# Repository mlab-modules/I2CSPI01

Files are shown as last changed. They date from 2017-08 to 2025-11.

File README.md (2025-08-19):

# I2CSPI01 - I2C to SPI bridge

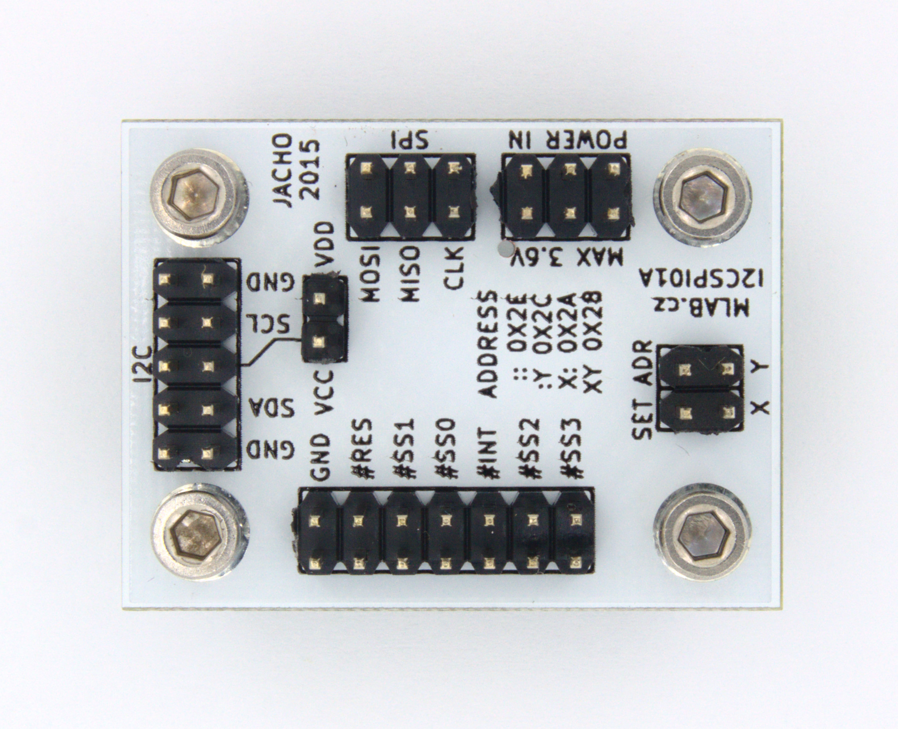
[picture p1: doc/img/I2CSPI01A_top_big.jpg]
I2CSPI01A


The I2CSPI01 module is designed for systems where a microcontroller with only an I2C interface needs to communicate with one or more SPI peripherals. It acts as a bridge that translates I2C commands into SPI signals, allowing integration of SPI devices such as ADCs, DACs, memory chips, or sensors into an I2C-based architecture. This simplifies wiring and reduces the number of required signals.

## Features

* I2C to SPI bridge based on SC18IS602B
* Supports up to four SPI slave devices
* Unused chip-select pins configurable as GPIO
* SPI clock modes: 0, 1, 2, 3
* SPI speed configurable: 58 kHz to 1.843 MHz
* GPIOs support multiple modes: quasi-bidirectional, push-pull, input-only, open-drain
* 200-byte internal buffer
* Operates as I2C slave and SPI master
* 3.3V supply voltage

## Specifications

| Parameter | Value |
| --- | --- |
| Power Supply | Max. 3.6 V |
| Dimensions | 40.13 x 30.00 x 16 mm |
| Interface | I2C (up to 400 kHz), SPI (up to 1.843 MHz) |
| IC Used | SC18IS602B |

## Assembly Notes

* One via must be drilled due to a PCB short.
* J5 header is not functional due to PCB layout issue.

## Resources

* [SC18IS602B Datasheet](https://www.nxp.com/docs/en/data-sheet/SC18IS602B.pdf)
* [Buy from UST](https://www.ust.cz/about/)

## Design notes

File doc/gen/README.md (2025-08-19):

# PCB

Board size: 29.97x40.13 mm (1.18x1.58 inches)

- This is the size of the rectangle that contains the board
- Thickness: 1.6 mm (63 mils)
- Material: FR4
- Finish: HAL
- Layers: 2
- Copper thickness: 35 µm

Solder mask: TOP / BOTTOM

- Color: Green

Silk screen: TOP / BOTTOM

- Color: White

# Important sizes

Clearance: 0.2 mm (8 mils)

Track width: 0.25 mm (10 mils)

- By design rules: 0.25 mm (10 mils)

Drill: 0.75 mm (30 mils)

- Vias: 0.75 mm (30 mils) [Design: 0.6 mm (24 mils)]
- Pads: 1.0 mm (39 mils)
- The above values are real drill sizes, they add 0.1 mm (4 mils) to plated holes (PTH)

Via: 0.89/0.64 mm (35/25 mils)

- By design rules: 0.89/0.51 mm (35/20 mils)
- Micro via: yes [0.51/0.13 mm (20/5 mils)]
- Buried/blind via: yes
- Total: 1 (thru: 1 buried/blind: 0 micro: 0)

Outer Annular Ring: 0.07 mm (3 mils)

- By design rules: 0.33 mm (13 mils)

Eurocircuits class: 10A
- Using min drill 0.75 mm for an OAR of 0.07 mm

# General stats

Components count: (SMD/THT)

- Top: 0/11 (THT)
- Bottom: 11/0 (SMD)

Defined tracks:

- 0.25 mm (10 mils)
- 0.38 mm (15 mils)
- 0.4 mm (16 mils)
- 0.51 mm (20 mils)
- 0.6 mm (24 mils)
- 0.7 mm (28 mils)

Used tracks:

- 0.25 mm (10 mils) (2) defined: yes
- 0.38 mm (15 mils) (109) defined: yes
- 0.51 mm (20 mils) (24) defined: yes

Defined vias:

Used vias:

- 0.89/0.64 mm (35/25 mils) (Count: 1, Aspect: 1.8 A) defined: no

Holes (excluding vias):

- 0.9 mm (35 mils) (42)
- 3.0 mm (118 mils) (4)

Oval holes:

Drill tools (including vias and computing adjusts and rounding):

- 0.75 mm (30 mils) (1)
- 1.0 mm (39 mils) (42)
- 3.1 mm (122 mils) (4)

Solder paste stats:

Using a paste with 87.75 % alloy, that has an specific gravity for the alloy of 7.4 g/cm³
and 1.0 g/cm³ for the flux. This paste has an specific gravity of  4.15 g/cm³.

The stencil thickness is  0.12 mm.

| Side | Pads with paste | Area [mm²] | Paste [g] |
|---|---|---|---|
| Total  | 36 | 34.52 | 0.17 |

Note: this is just an approximation to the theoretical value. Margins of the solder mask and waste aren't computed.

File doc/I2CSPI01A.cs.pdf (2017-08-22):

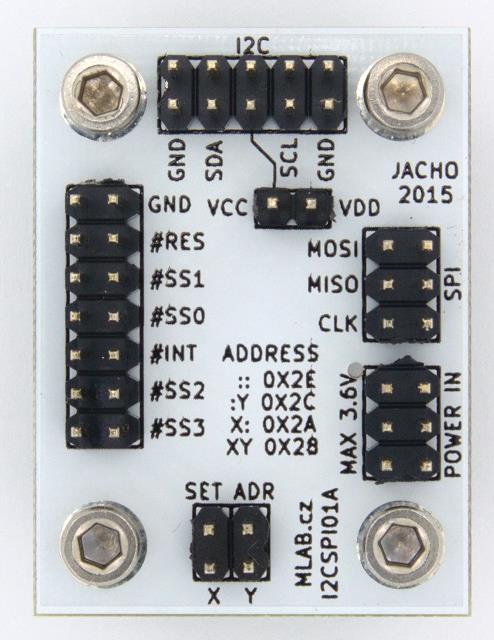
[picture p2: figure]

I2CSPI01A / 2016-02-26 / jacho/ http://www.mlab.cz | 1 / 4
I2CSPI01A | MLAB

# I2C - SPI převodník

Jan Chroust

Modul umožňuje připojení až čtyř zařízení na sběrnici SPI současně. Případné nevyužité piny mohou sloužit jako GPIO.

# 1. Technické parametry

Parametr | Hodnota | Poznámka
Napájení | Max. 3,6 V
Integrovaný obvod | SC18IS602B
Rozhraní | I2C, SPI
Hlavní využití | I2C/SPI převodník
Rozměry | 40.13 x 30.00 x 16 mm | Výška nad základní deskou

I2CSPI01A | MLAB

# 2. Popis konstrukce

## 2.1. Zapojení

I2CSPI01A | MLAB

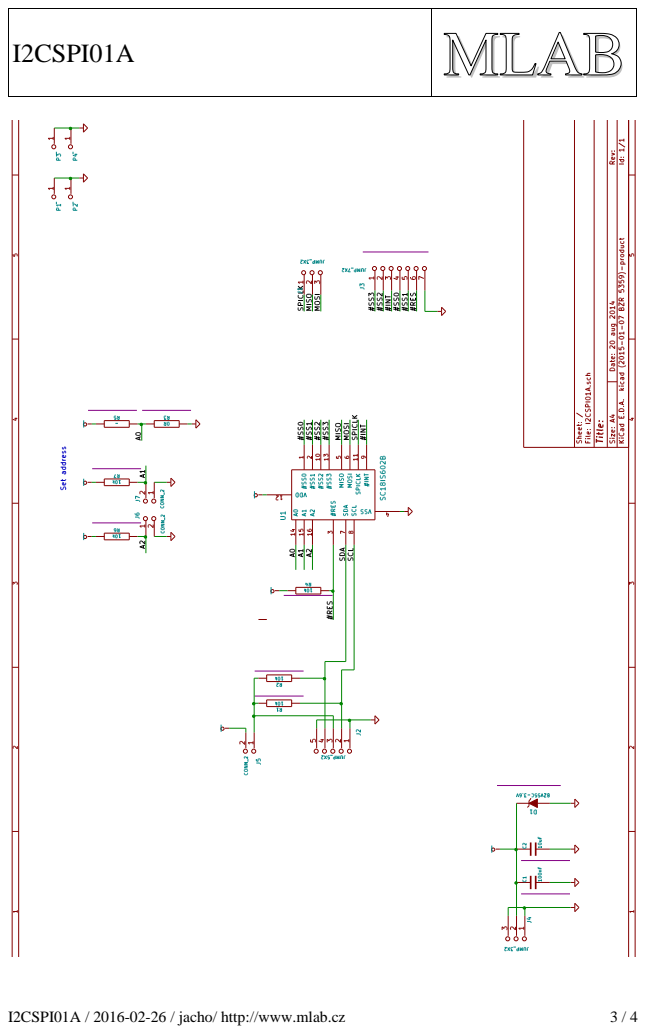
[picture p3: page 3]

I2CSPI01A | MLAB

# 3. Osazení a oživení

## 3.1. Osazení

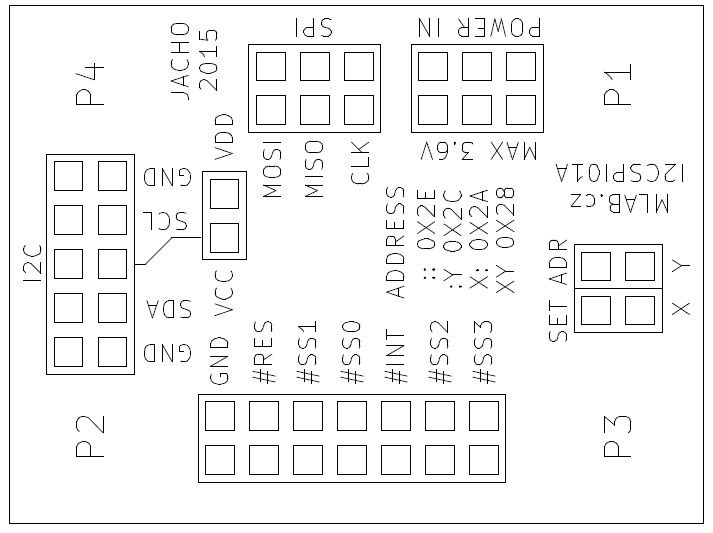
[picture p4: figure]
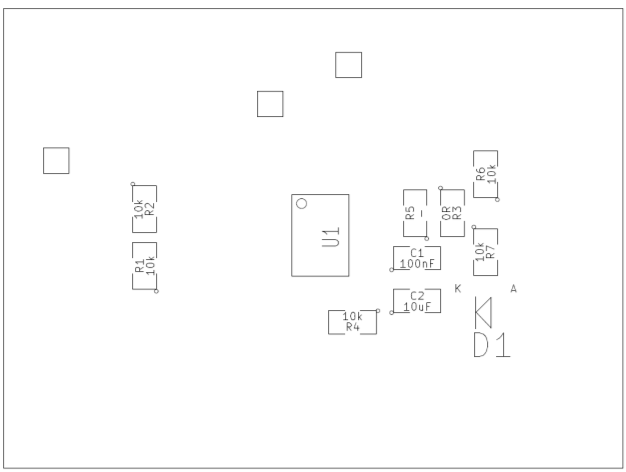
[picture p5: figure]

Označení | Typ | Pouzdro | Počet
J1 | JUMP_3X2 | Pin_Header_Straight_2x03 | 1
R1,R2,R4,R6,R7 | 10k | SMD-0805 | 5
C1 | 100nF | SMD-0805 | 1
C2 | 10uF | SMD-0805 | 1
R3 | 0R | SMD-0805 | 1
R5 | - | SMD-0805 | 1
U1 | SC18IS602B | TSSOP-16 | 1
J4 | JUMP_3X2 | Pin_Header_Straight_2x03 | 1
J3 | JUMP_7X2 | Pin_Header_Straight_2x07 | 1
J2 | JUMP_5X2 | Pin_Header_Straight_2x05 | 1
P1,P2,P3,P4 | _ | MountingHole_3mm | 4
J5,J6,J7 | CONN_2 | Pin_Header_Straight_1x02 | 3
D1 | BZV55C-3,6V | Diode-MiniMELF_Standard | 1

Je potřeba odvrtat jediný prokov na PCB (kvůli zkratu na PCB). Funkce hřebínku J5 odpadá.

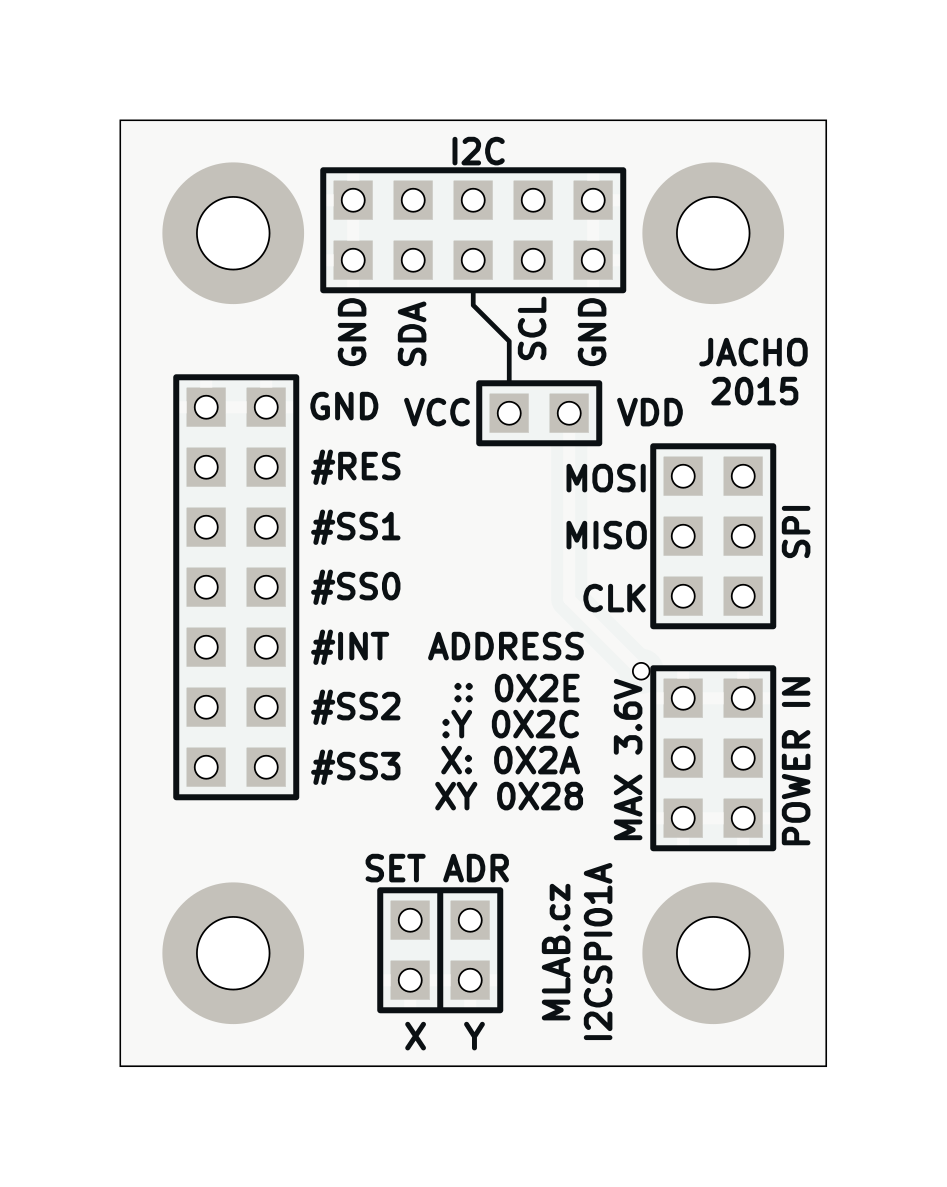
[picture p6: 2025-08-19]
doc/gen/img/I2CSPI01-top.png

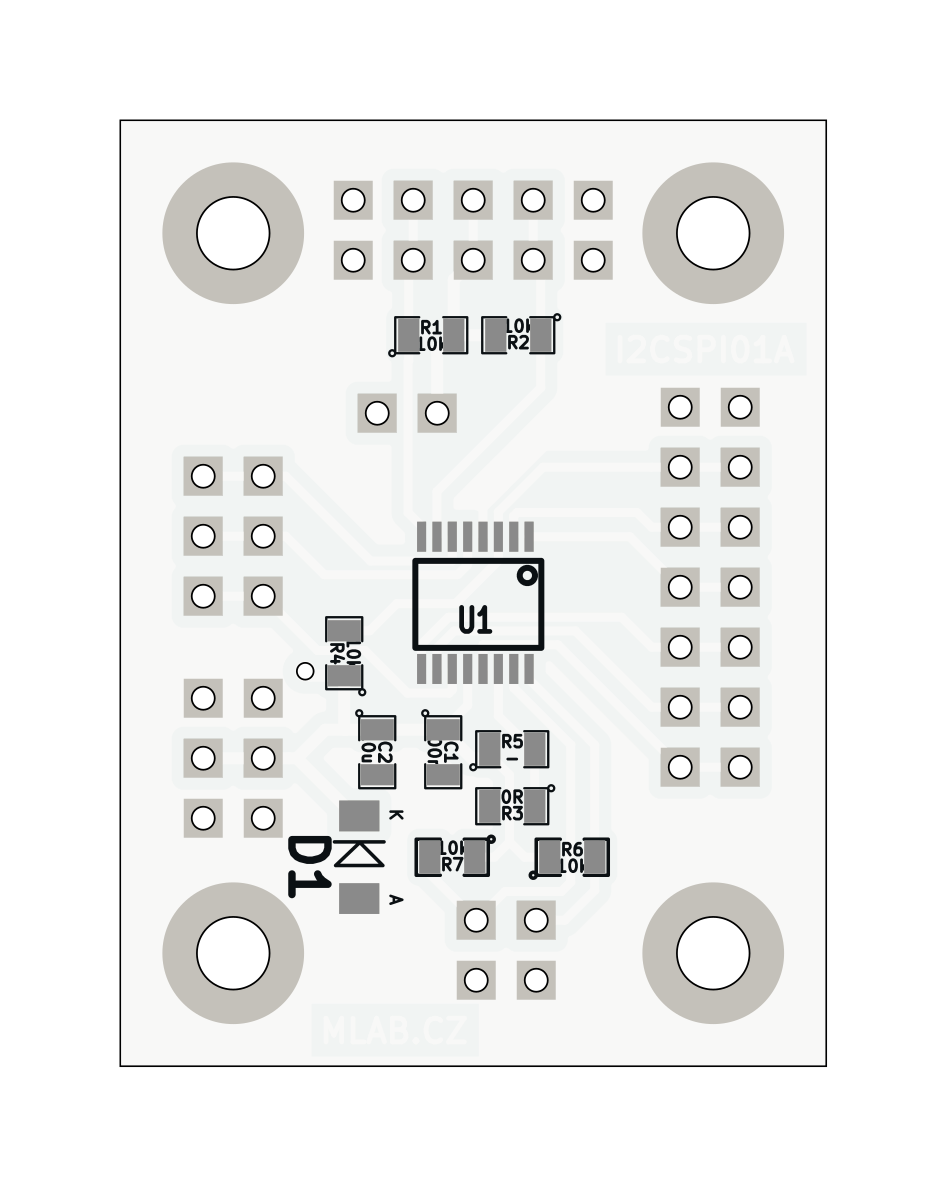
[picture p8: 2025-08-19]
doc/gen/img/I2CSPI01-bottom.png

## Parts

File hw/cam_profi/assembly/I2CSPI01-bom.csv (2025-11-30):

Component | Description | Part | References | Value | Footprint | Quantity Per PCB | Datasheet
1 |  | C_3 | C1 | 100nF | SMD-0805 | 1 | ~
2 |  | C_4 | C2 | 10uF | SMD-0805 | 1 | ~
3 |  | ZENER_2 | D1 | BZV55C-3,6V | Diode-MiniMELF_Standard | 1 | ~
4 |  | CONN_2_6 | J5 | CONN_2 | Pin_Header_Straight_1x02 | 1
5 |  | CONN_2_4 | J6 | CONN_2 | Pin_Header_Straight_1x02 | 1
6 |  | CONN_2_5 | J7 | CONN_2 | Pin_Header_Straight_1x02 | 1
7 |  | JUMP_3X2_3 | J1 | JUMP_3X2 | Pin_Header_Straight_2x03 | 1
8 |  | JUMP_3X2_4 | J4 | JUMP_3X2 | Pin_Header_Straight_2x03 | 1
9 |  | JUMP_5X2_2 | J2 | JUMP_5X2 | Pin_Header_Straight_2x05 | 1
10 |  | JUMP_7X2_2 | J3 | JUMP_7X2 | Pin_Header_Straight_2x07 | 1 | ~
11 |  | R_14 | R3 | 0R | SMD-0805 | 1 | ~
12 |  | R_10 | R1 | 10k | SMD-0805 | 1 | ~
13 |  | R_9 | R2 | 10k | SMD-0805 | 1 | ~
14 |  | R_8 | R4 | 10k | SMD-0805 | 1 | ~
15 |  | R_11 | R6 | 10k | SMD-0805 | 1 | ~
16 |  | R_12 | R7 | 10k | SMD-0805 | 1 | ~
17 |  | R_13 | R5 | - | SMD-0805 | 1 | ~
18 |  | SC18IS602B_2 | U1 | SC18IS602B | TSSOP-16 | 1

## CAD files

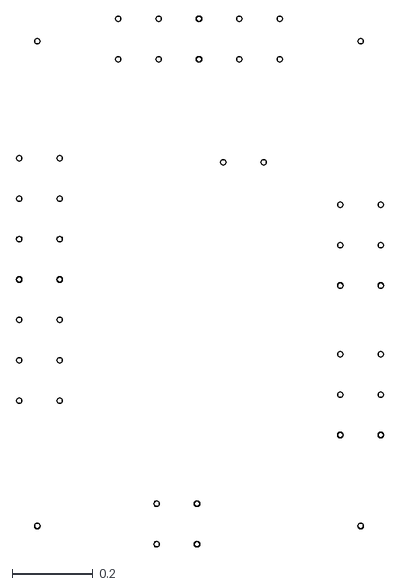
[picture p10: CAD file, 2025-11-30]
doc/gen/dxf/I2CSPI01-User_Eco1.dxf
0.909 x 1.31

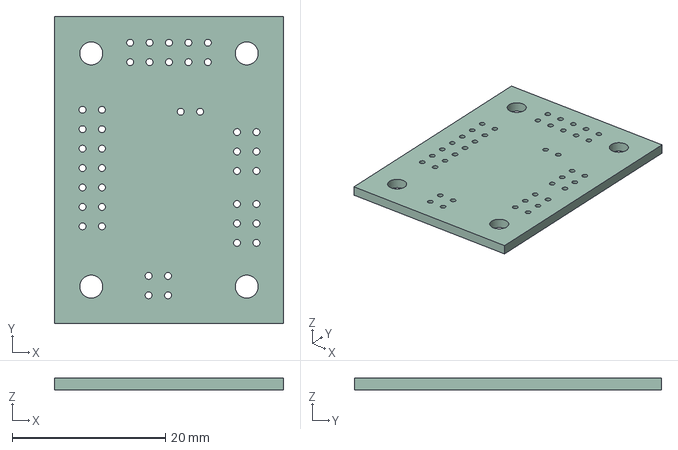
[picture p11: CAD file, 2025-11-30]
doc/gen/I2CSPI01.step
30.0 x 40.1 x 1.51 mm

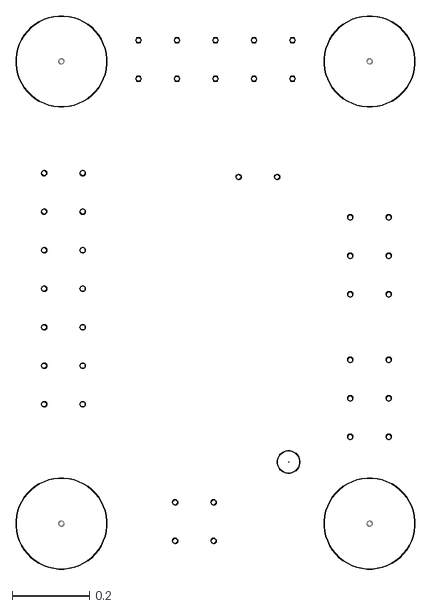
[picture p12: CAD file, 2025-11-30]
doc/gen/dxf/I2CSPI01-B_Adhesive.dxf
1.04 x 1.44

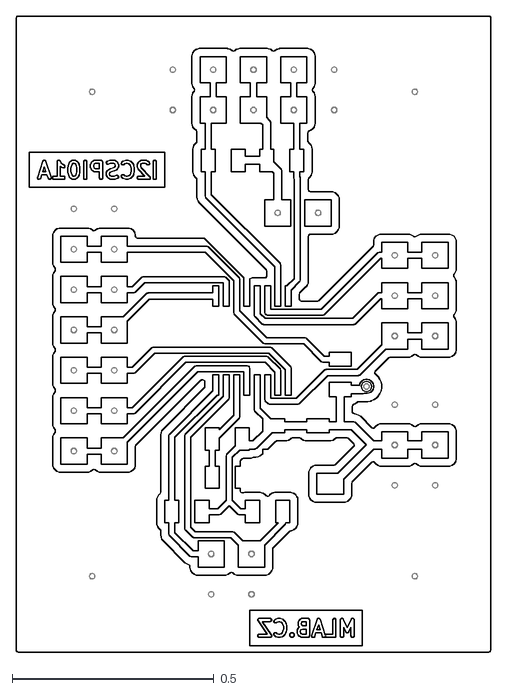
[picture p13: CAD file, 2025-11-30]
doc/gen/dxf/I2CSPI01-B_Cu.dxf
1.18 x 1.58

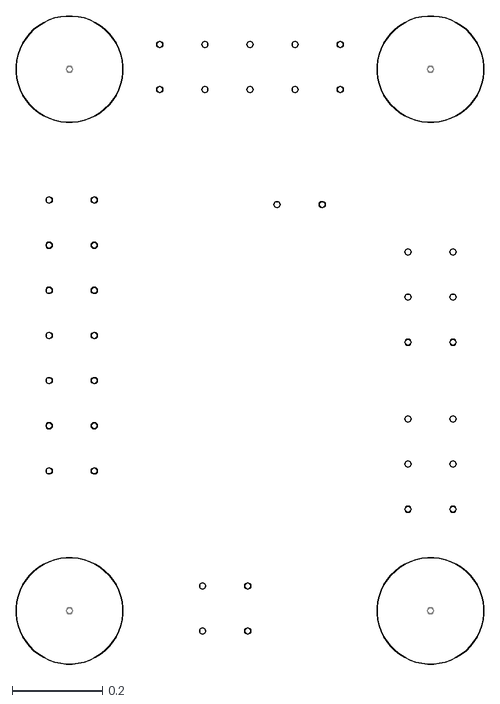
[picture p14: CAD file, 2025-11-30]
doc/gen/dxf/I2CSPI01-F_Adhesive.dxf
1.04 x 1.44

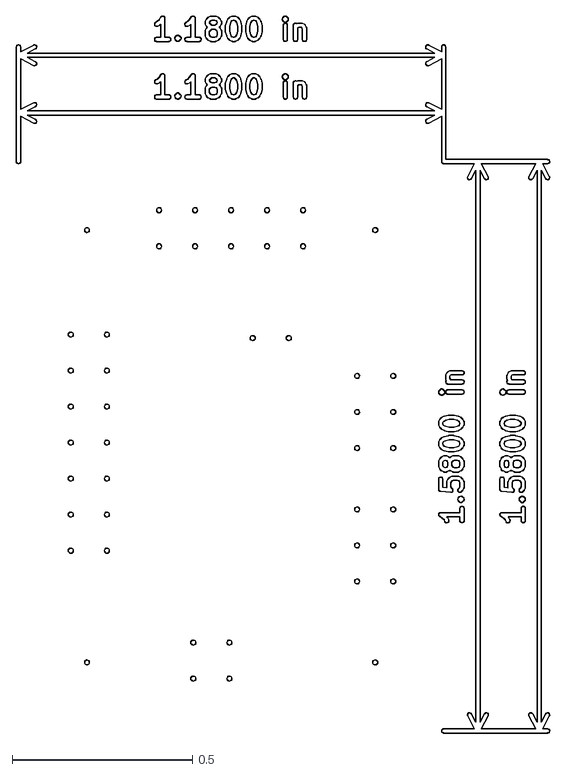
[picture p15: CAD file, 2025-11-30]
doc/gen/dxf/I2CSPI01-User_Drawings.dxf
1.48 x 1.99

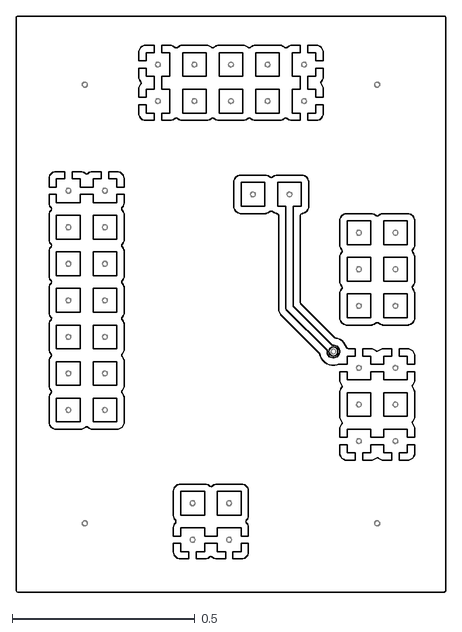
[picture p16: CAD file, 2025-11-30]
doc/gen/dxf/I2CSPI01-F_Cu.dxf
1.18 x 1.58

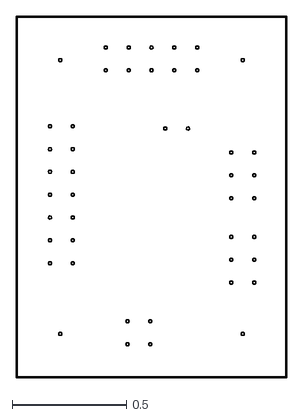
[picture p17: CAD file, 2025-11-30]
doc/gen/dxf/I2CSPI01-Edge_Cuts.dxf
1.18 x 1.58

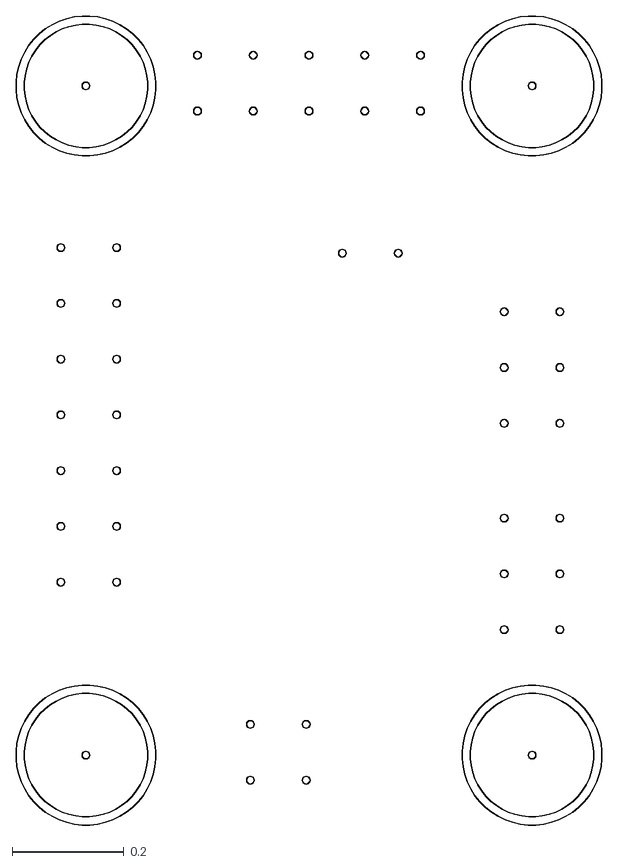
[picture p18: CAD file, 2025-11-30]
doc/gen/dxf/I2CSPI01-User_Comments.dxf
1.05 x 1.45

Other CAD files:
doc/gen/dxf/I2CSPI01-B_Mask.dxf
doc/gen/dxf/I2CSPI01-B_Paste.dxf
doc/gen/dxf/I2CSPI01-B_Silkscreen.dxf
doc/gen/dxf/I2CSPI01-F_Mask.dxf
doc/gen/dxf/I2CSPI01-F_Paste.dxf
doc/gen/dxf/I2CSPI01-F_Silkscreen.dxf

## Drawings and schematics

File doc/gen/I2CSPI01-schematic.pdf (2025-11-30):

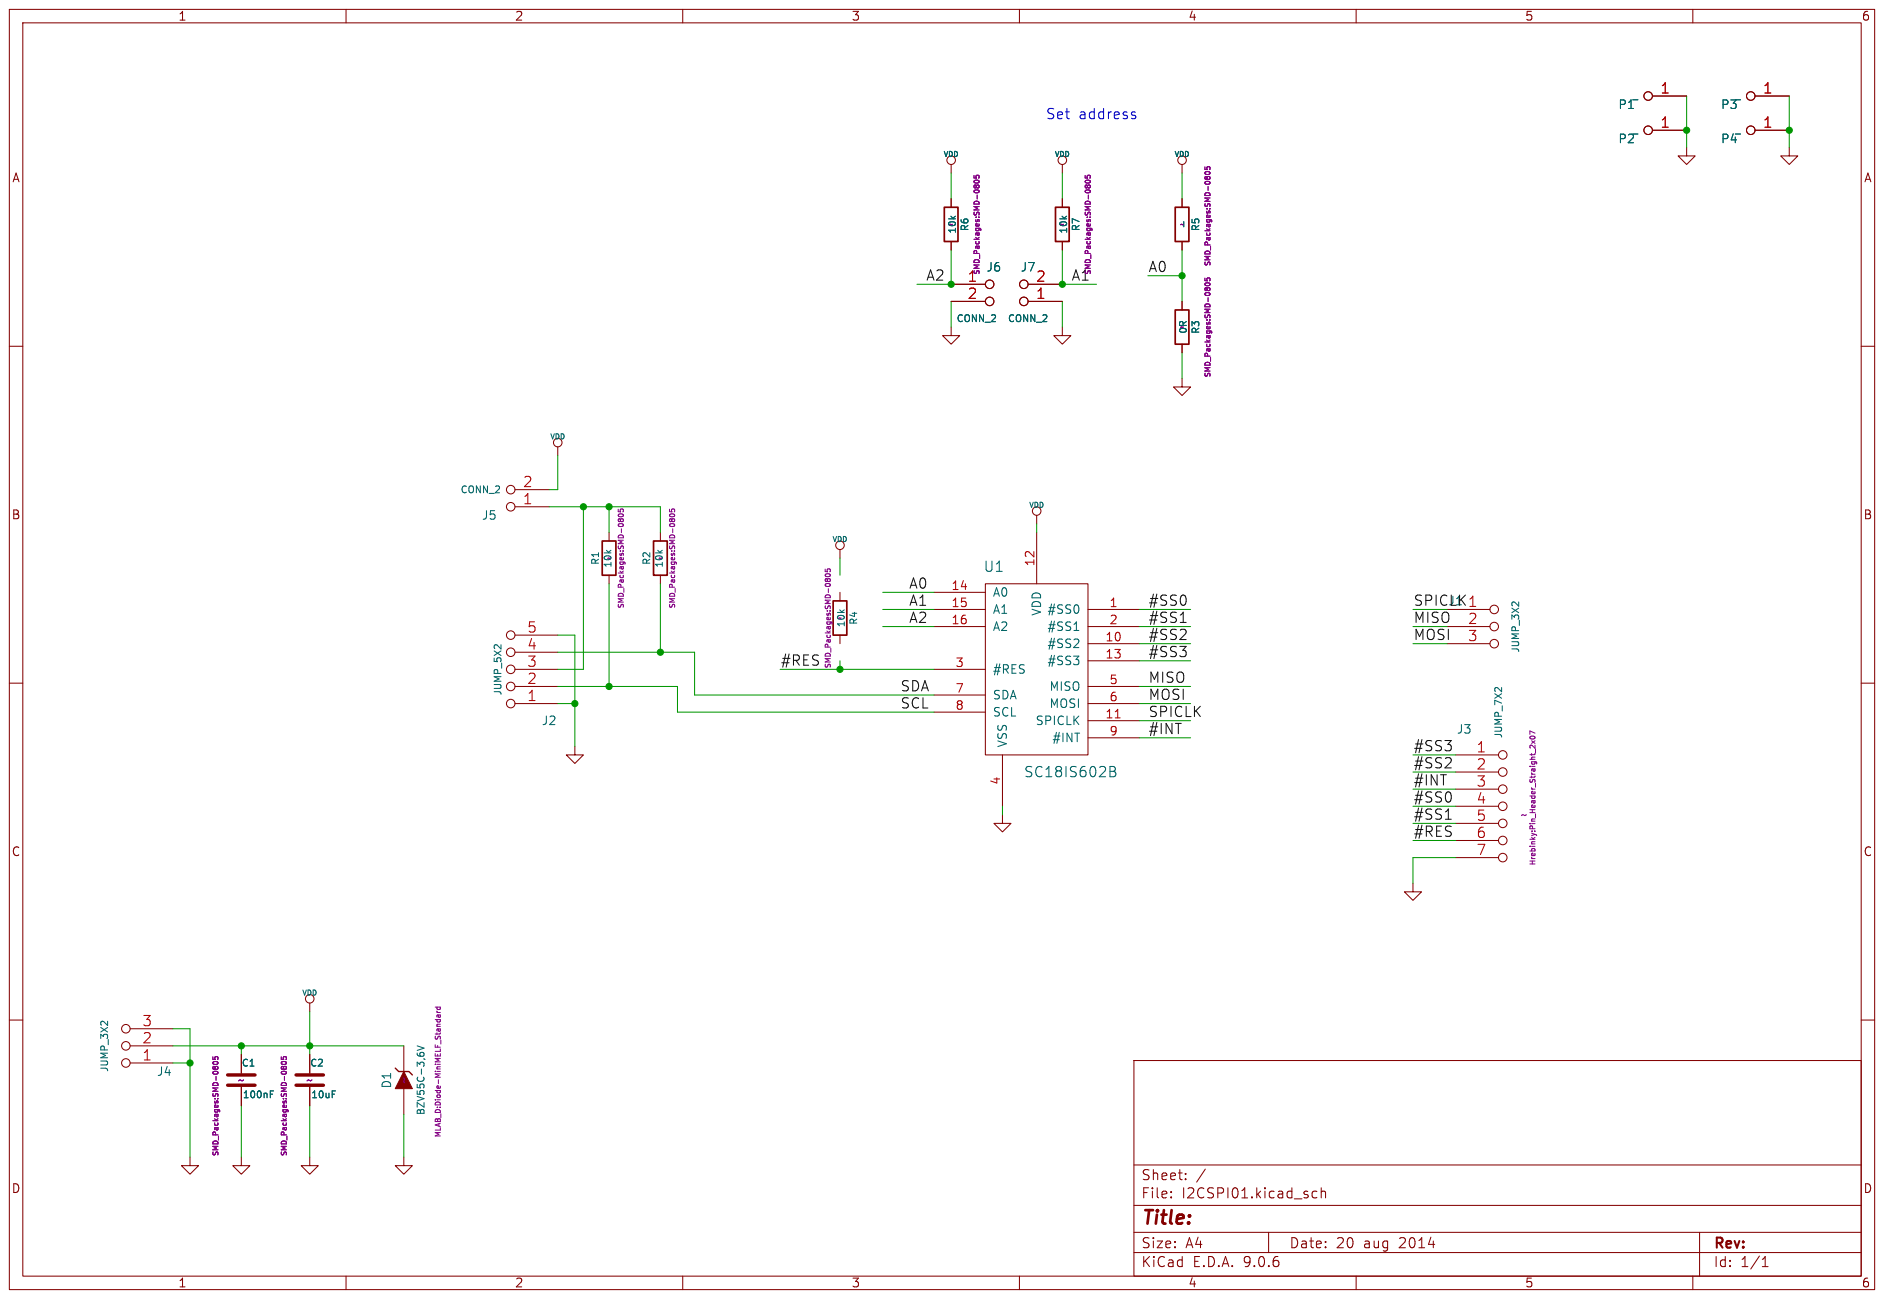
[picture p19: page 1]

Id: 1/1 Title: File: I2CSPI01.kicad_sch Sheet: / C1

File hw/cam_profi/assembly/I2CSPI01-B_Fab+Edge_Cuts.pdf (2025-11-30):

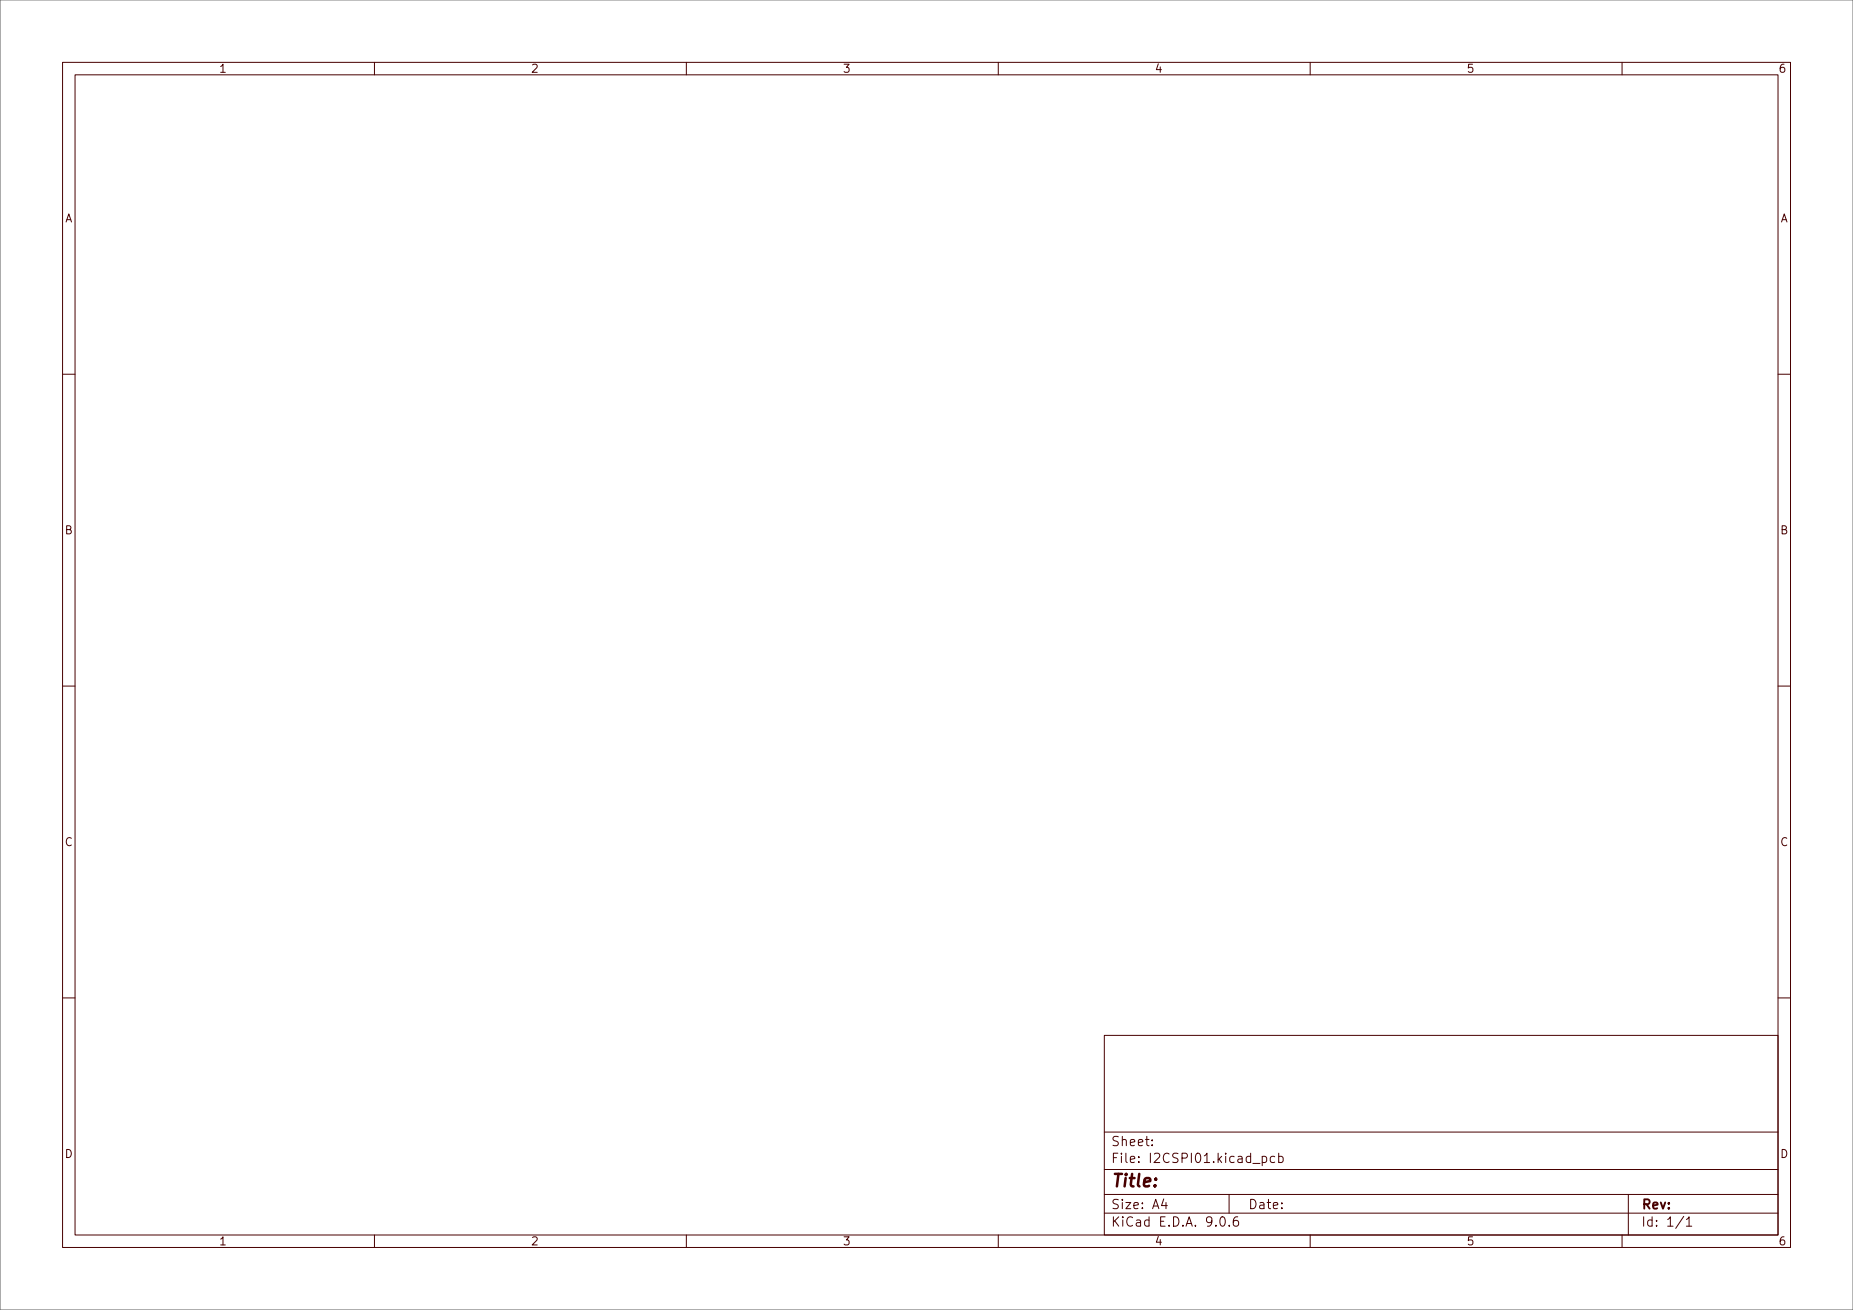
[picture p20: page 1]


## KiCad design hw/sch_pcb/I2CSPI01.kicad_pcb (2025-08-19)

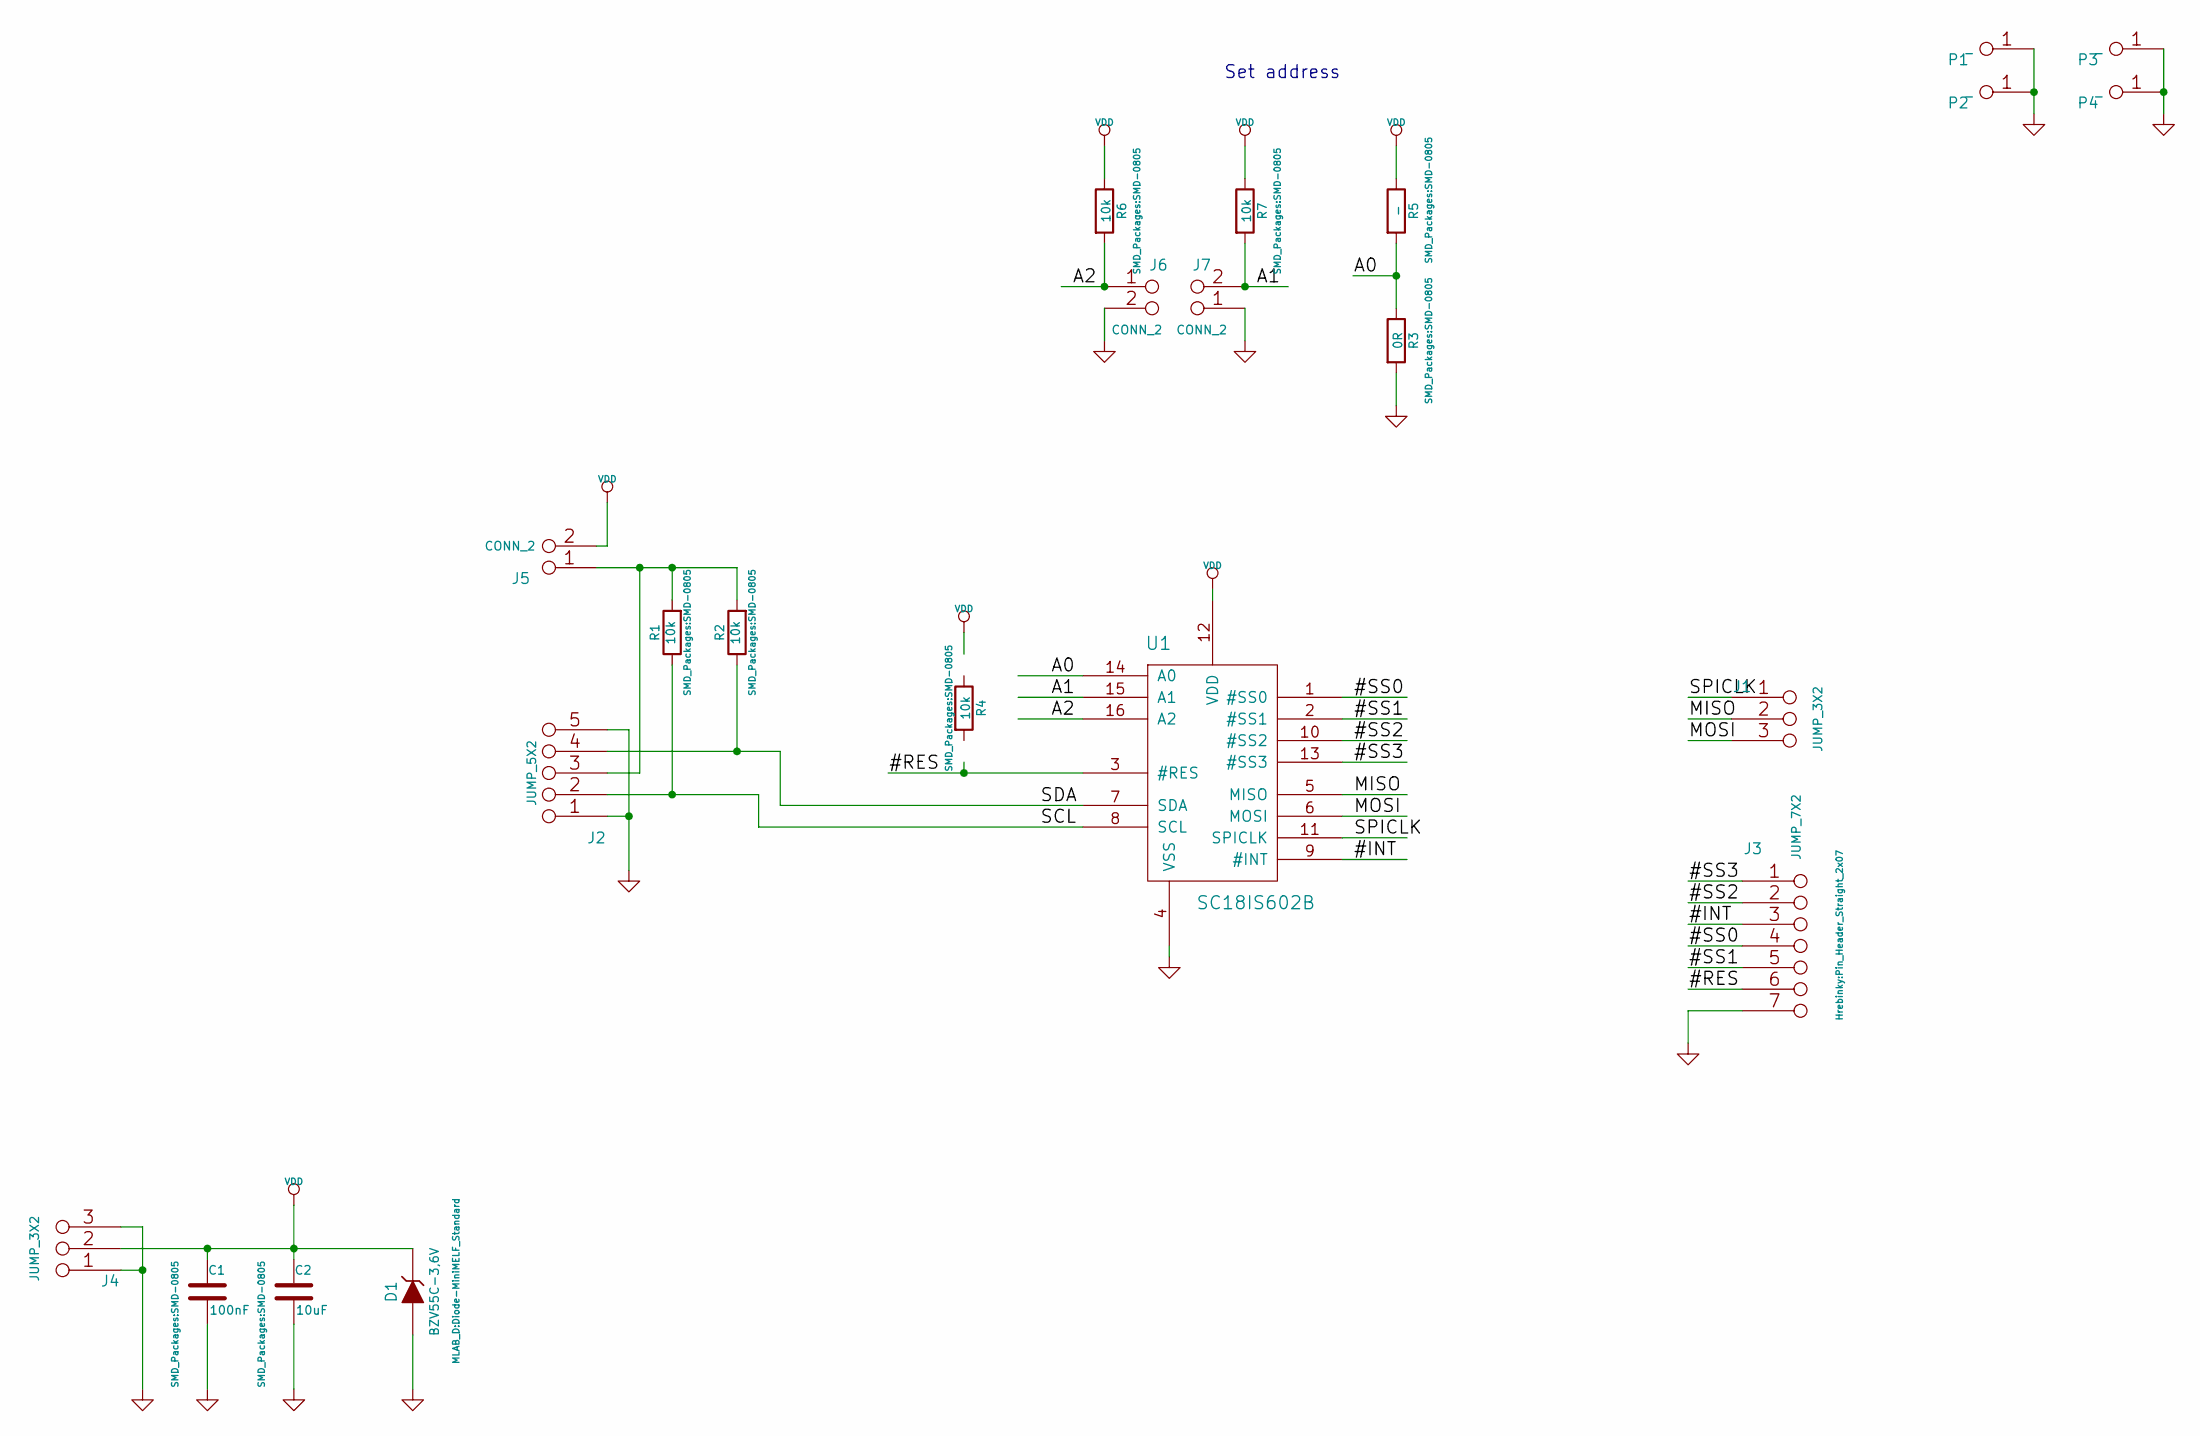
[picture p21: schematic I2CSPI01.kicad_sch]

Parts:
C1: 100nF; SMD-0805
C2: 10uF; SMD-0805
D1: BZV55C-3,6V; Diode-MiniMELF_Standard
J1, J4: JUMP_3X2; Pin_Header_Straight_2x03
J2: JUMP_5X2; Pin_Header_Straight_2x05
J3: JUMP_7X2; Pin_Header_Straight_2x07
J5, J6, J7: CONN_2; Pin_Header_Straight_1x02
P1, P2, P3, P4: _; MountingHole_3mm
R1, R2, R4, R6, R7: 10k; SMD-0805
R3: 0R; SMD-0805
R5: -; SMD-0805
U1: SC18IS602B; TSSOP-16

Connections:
/#INT: J3.3, J3.12, U1.9 (#INT)
/#RES: J3.6, J3.9, R4.2, U1.3 (#RES)
/#SS0: J3.4, J3.11, U1.1 (#SS0)
/#SS1: J3.5, J3.10, U1.2 (#SS1)
/#SS2: J3.2, J3.13, U1.10 (#SS2)
/#SS3: J3.1, J3.14, U1.13 (#SS3)
/A0: R3.1, R5.2, U1.14 (A0)
/A1: J7.2 (PM), R7.2, U1.15 (A1)
/A2: J6.1, R6.2, U1.16 (A2)
/MISO: J1.2 (1), J1.5, U1.5 (MISO)
/MOSI: J1.3, J1.4, U1.6 (MOSI)
/SCL: J2.2, J2.9, R1.1, U1.8 (SCL)
/SDA: J2.4, J2.7, R2.1, U1.7 (SDA)
/SPICLK: J1.1, J1.6, U1.11 (SPICLK)
GND: C1.2, C2.2, D1.1 (A), J2.1, J2.5, J2.6, J2.10, J3.7, J3.8, J4.1, J4.3, J4.4, J4.6, J6.2 (PM), J7.1, P1.1, P2.1, P3.1, P4.1, R3.2, U1.4 (VSS)
unnamed: J2.3, J2.8, J5.1, R1.2, R2.2
VDD: C1.1, C2.1, D1.2 (K), J4.2 (1), J4.5, J5.2 (PM), R4.1, R5.1, R6.1, R7.1, U1.12 (VDD)

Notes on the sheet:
Set address

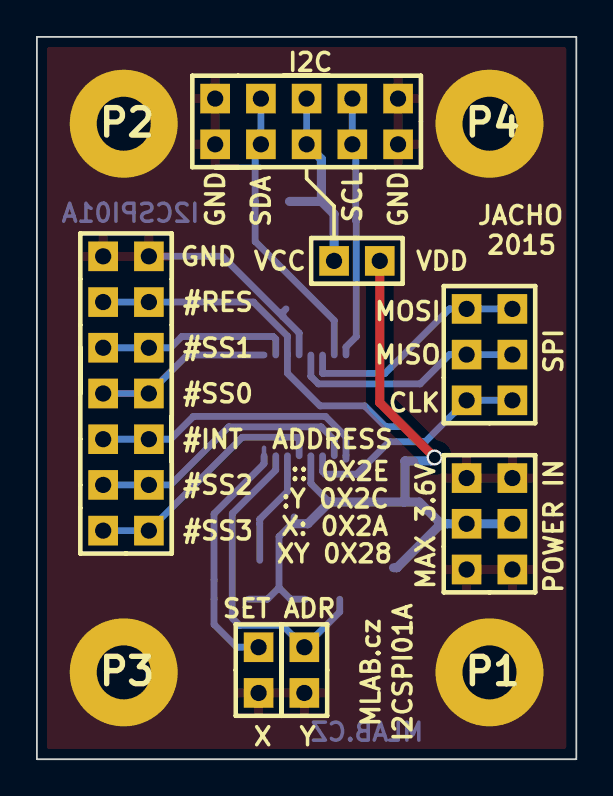
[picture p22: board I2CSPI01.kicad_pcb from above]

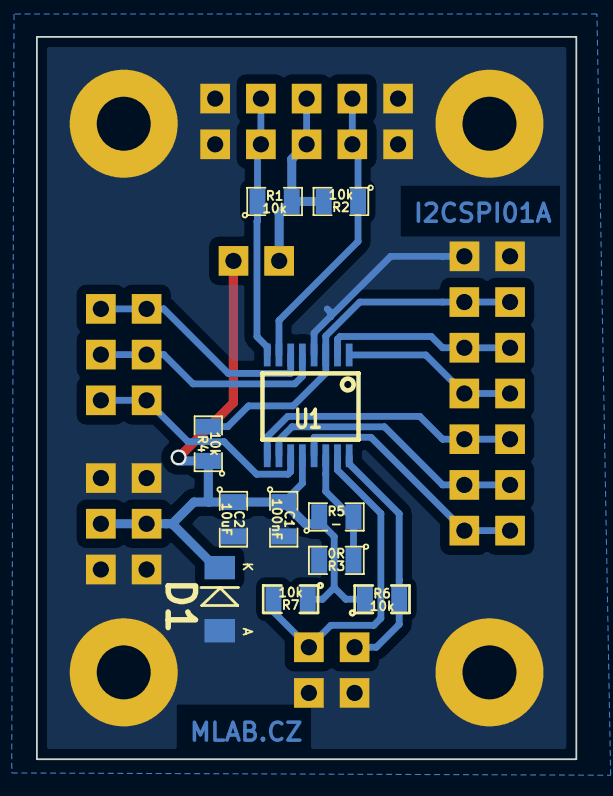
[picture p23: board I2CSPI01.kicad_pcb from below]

Board: 2 copper layers, 30.0 x 40.1 mm, 22 parts (11 on the bottom side), 17 nets.

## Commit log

2017-08-22 rename category folders
    [I2CSPI01A.kicad_pcb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]
2017-08-22 rename files and module folders
    [I2CSPI01A.kicad_pcb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]
2017-08-22 create hw folder
    [I2CSPI01A.kicad_pcb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]
2017-11-02 [MLABweb] 2017-11-02 00:09:53 I2CSPI01A
2023-07-05 automated commit; rename source files to new naming convence
    [I2CSPI01.kicad_pcb]
2025-08-19 Update KiCAD workflow and project data.
    [I2CSPI01.kicad_pcb, I2CSPI01A.kicad_sch, I2CSPI01A.sch]
2025-08-19 Rename KiCAD project.
    [I2CSPI01.kicad_sch]
2025-08-19 Update actions products
    [I2CSPI01-B_Adhesive.dxf, I2CSPI01-B_Courtyard.dxf, I2CSPI01-B_Cu.dxf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]
